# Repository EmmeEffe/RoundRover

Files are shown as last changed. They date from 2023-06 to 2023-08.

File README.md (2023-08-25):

# RoundRover
Star Wars BB8-style 3D Printed Robot

Designed and developed by [Lorenzo Cicali](https://www.github.com/Lorentz99), [Ginevra Dazzi](https://www.github.com/Gine99), [Tommaso Matteuzzi](https://www.github.com/tommasomatt) and [Martino Falorni](https://www.github.com/EmmeEffe),

---
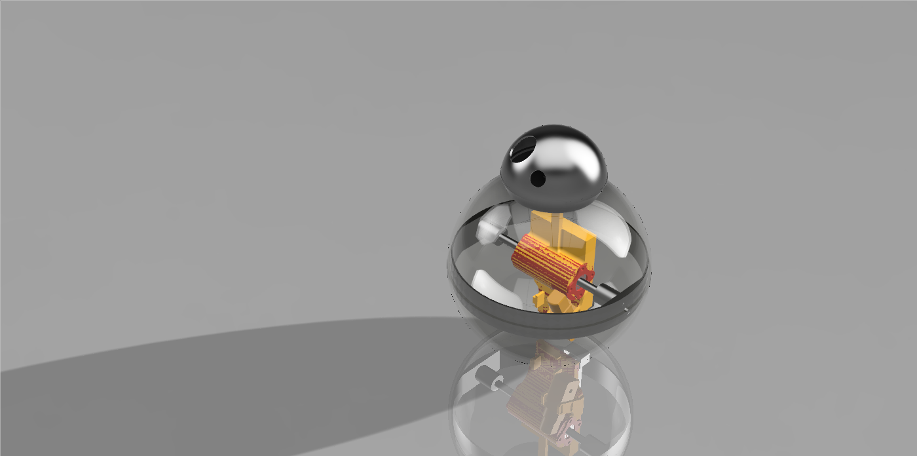
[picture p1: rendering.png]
rendering


## Goal
The project has been realized for the Automation Control Laboratory exam at University of Florence.

You can find the video of the project below: 

Design of a Spherical Robot BB8 with Arduino and Simulink (http://www.youtube.com/watch?v=LbQrJQIPuXo "Design of a Spherical Robot BB8 with Arduino and Simulink")

## Printing
You can use a 3D FDM Printer to print all the pieces for the project. 
We have printed them in PLA.

You can find the files in the [StlFiles](StlFiles/) folder.

You have to fill the balancer with lead balls ad glue the cover onto it:
- [Balancer Leg](StlFiles/balancer_leg.stl)
- [Balancer Cover](StlFiles/balancer_cover.stl)

Then print the transmission gears. Thoose are made for a 2.5mm belt
- [Big Gear](StlFiles/bigGear.stl)
- [Small Gear](StlFiles/smallGear.stl)

Then print the main body with the external ring
- [Main Body](StlFiles/body.stl)
- [External Ring](StlFiles/ring.stl)
- [Bearing Holder](StlFiles/bearingHolder.stl) (print 2 times)

## Parts
- Mechanic Hardware
  - 2 x plastic semisphere, diameter 200 mm
  - 1x Metal shaft, 160 mm, 8 mm ø
  - 2x Metal ball bearing, 8x22x7mm
  - 1x Transmission belt 2.5T
  - fishing Lead weights
  - Neodimium Magnets
  - bolts and nuts
  - threaded inserts for 3d prints
- Electronic Hardware
  - 9V battery
  - H-bridge board MX1616H
  - ESP32 board
  - IMU system MPU-6050
  - Servomotor 9g
  - Gear motor, DC, supply voltage 3-12 Volt, 200 rpm

## Circuit
We have realized the circuit on a perfboard following the schematic below:

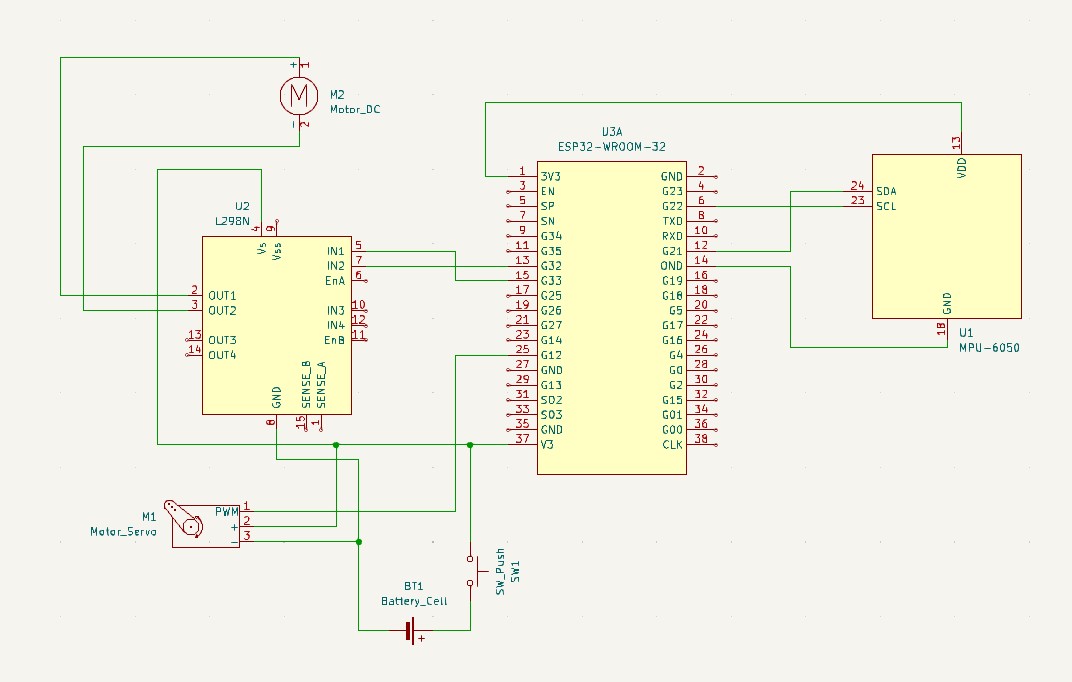
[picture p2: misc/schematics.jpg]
schematics


## Software 
The software is coded in Simulink. You can find all the code in the [SimulinkFiles](SimulinkFiles) folder.

[controlSystem.slx](SimulinkFiles/controlSystem.slx) has to be loaded onto the ESP32 board, [RemoteController.slx](SimulinkFiles/RemoteController.slx) will go on an Android device and is used to control the robot.

# Authors
Designed and developed by [Lorenzo Cicali](https://www.github.com/Lorentz99), [Ginevra Dazzi](https://www.github.com/Gine99), [Tommaso Matteuzzi](https://www.github.com/tommasomatt) and [Martino Falorni](https://www.github.com/EmmeEffe)

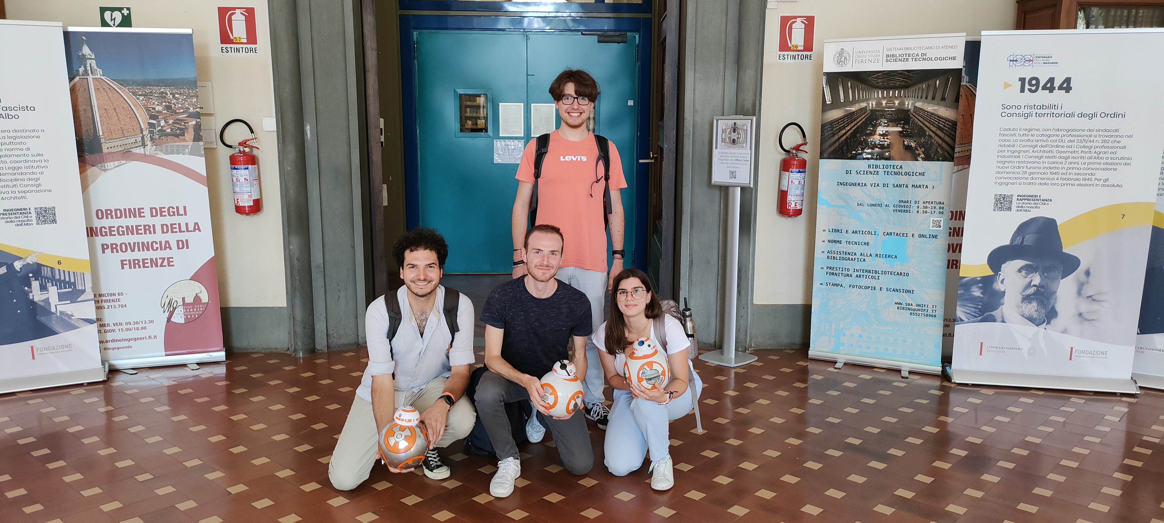
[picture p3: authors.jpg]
authors


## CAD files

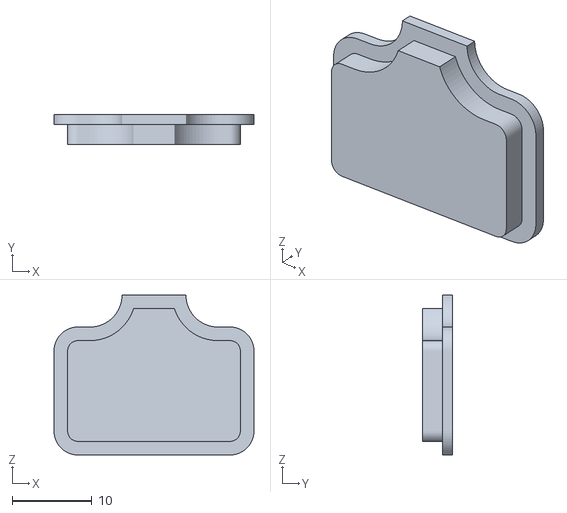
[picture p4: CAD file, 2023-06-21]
StlFiles/balancer_cover.stl
25.0 x 3.70 x 20.0

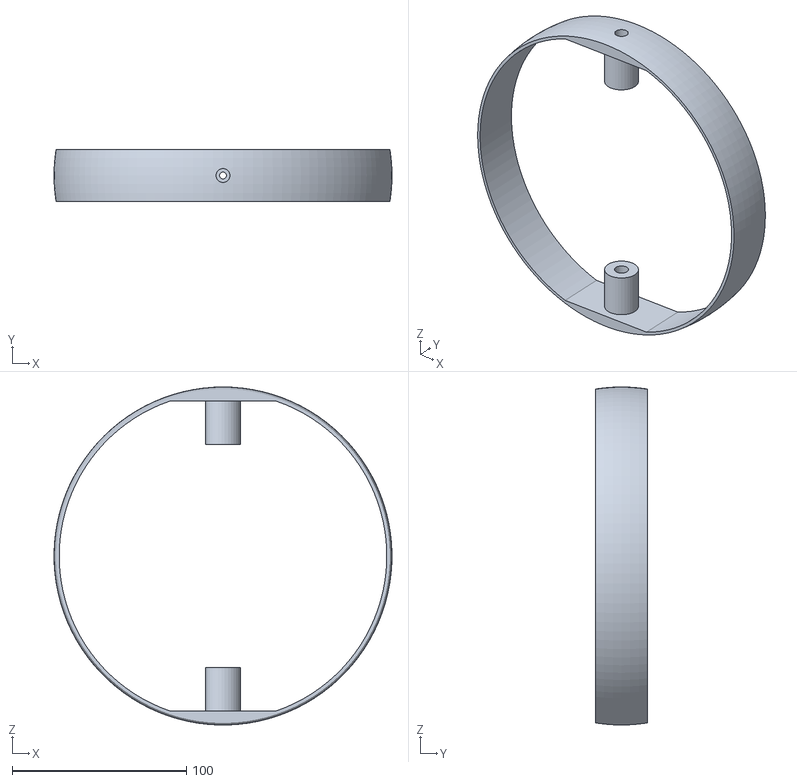
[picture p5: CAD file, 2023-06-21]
StlFiles/ring.stl
194.0 x 30.0 x 193.8

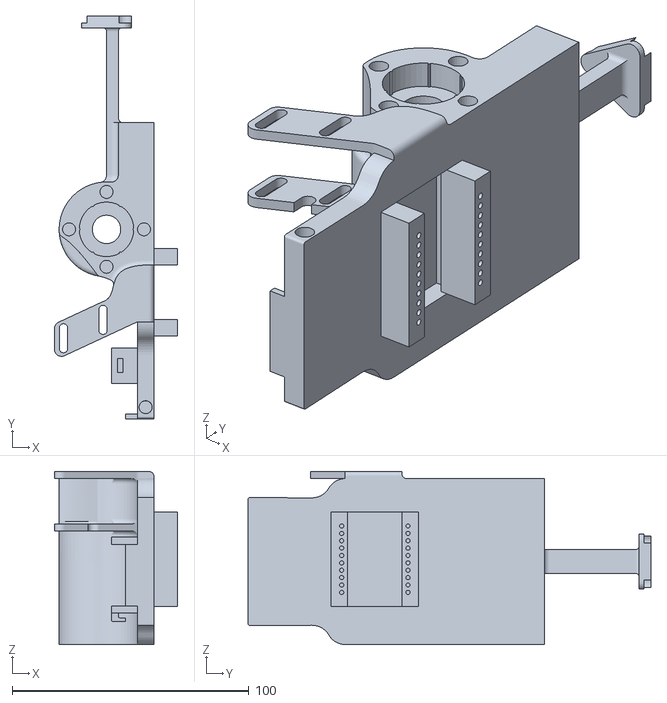
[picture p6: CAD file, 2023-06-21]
StlFiles/body.stl
52.0 x 170.0 x 73.0

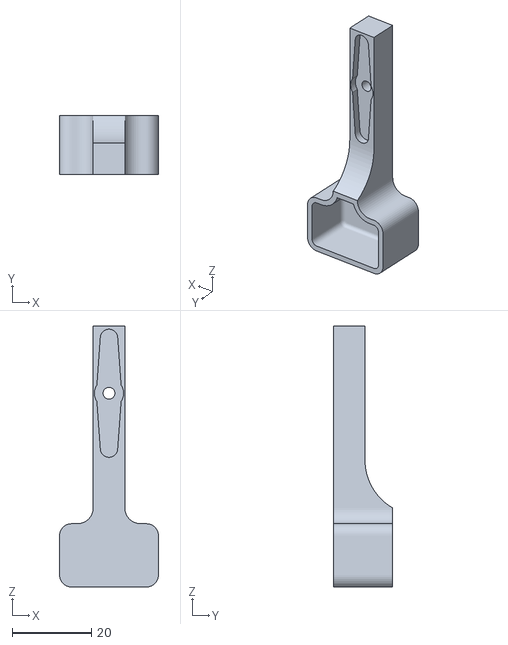
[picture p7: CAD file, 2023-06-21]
StlFiles/balancer_leg.stl
25.0 x 15.0 x 66.0

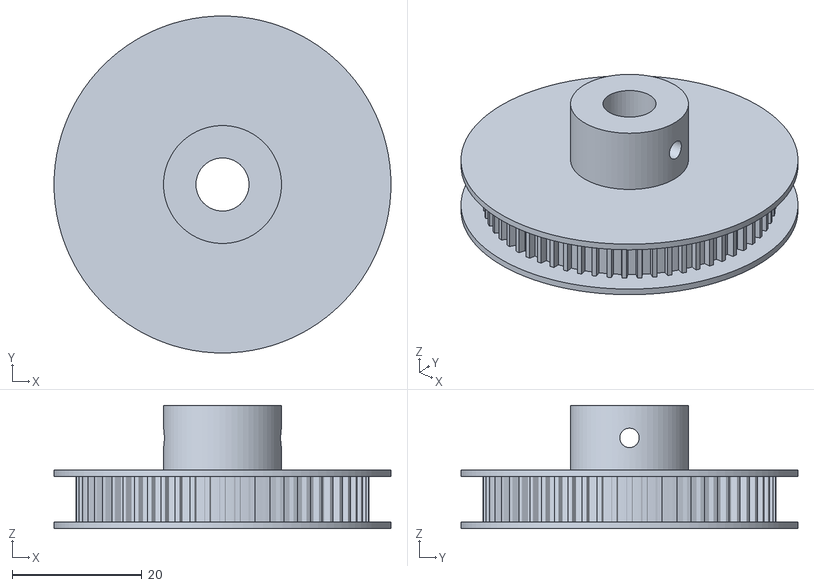
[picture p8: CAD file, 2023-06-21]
StlFiles/bigGear.stl
52.0 x 52.0 x 19.0

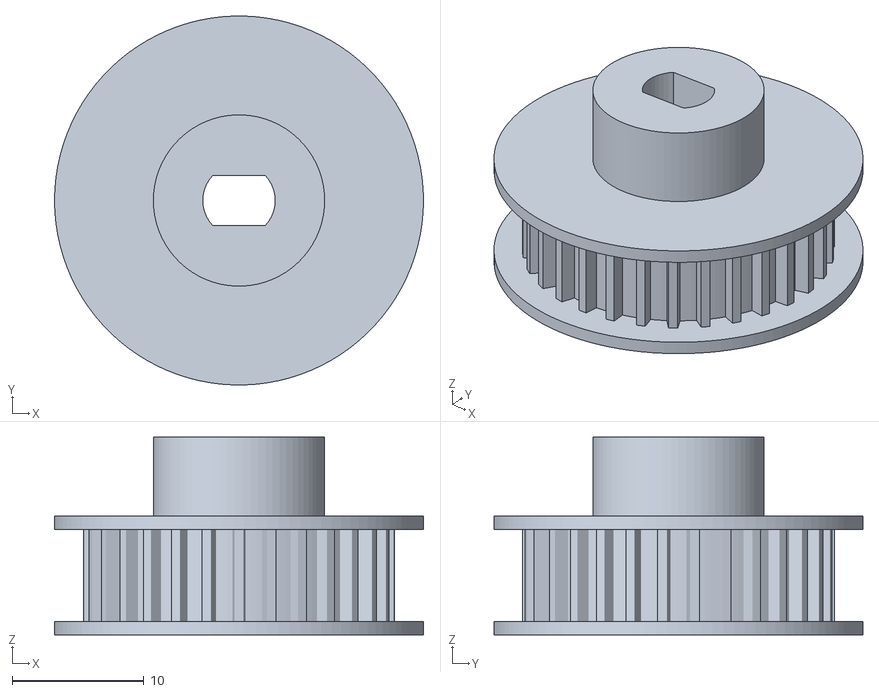
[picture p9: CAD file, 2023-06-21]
StlFiles/smallGear.stl
28.0 x 28.0 x 15.0

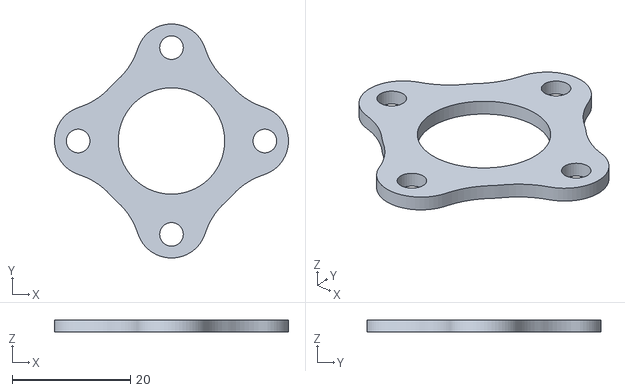
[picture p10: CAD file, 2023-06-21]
StlFiles/bearingHolder.stl
39.6 x 39.6 x 2.00

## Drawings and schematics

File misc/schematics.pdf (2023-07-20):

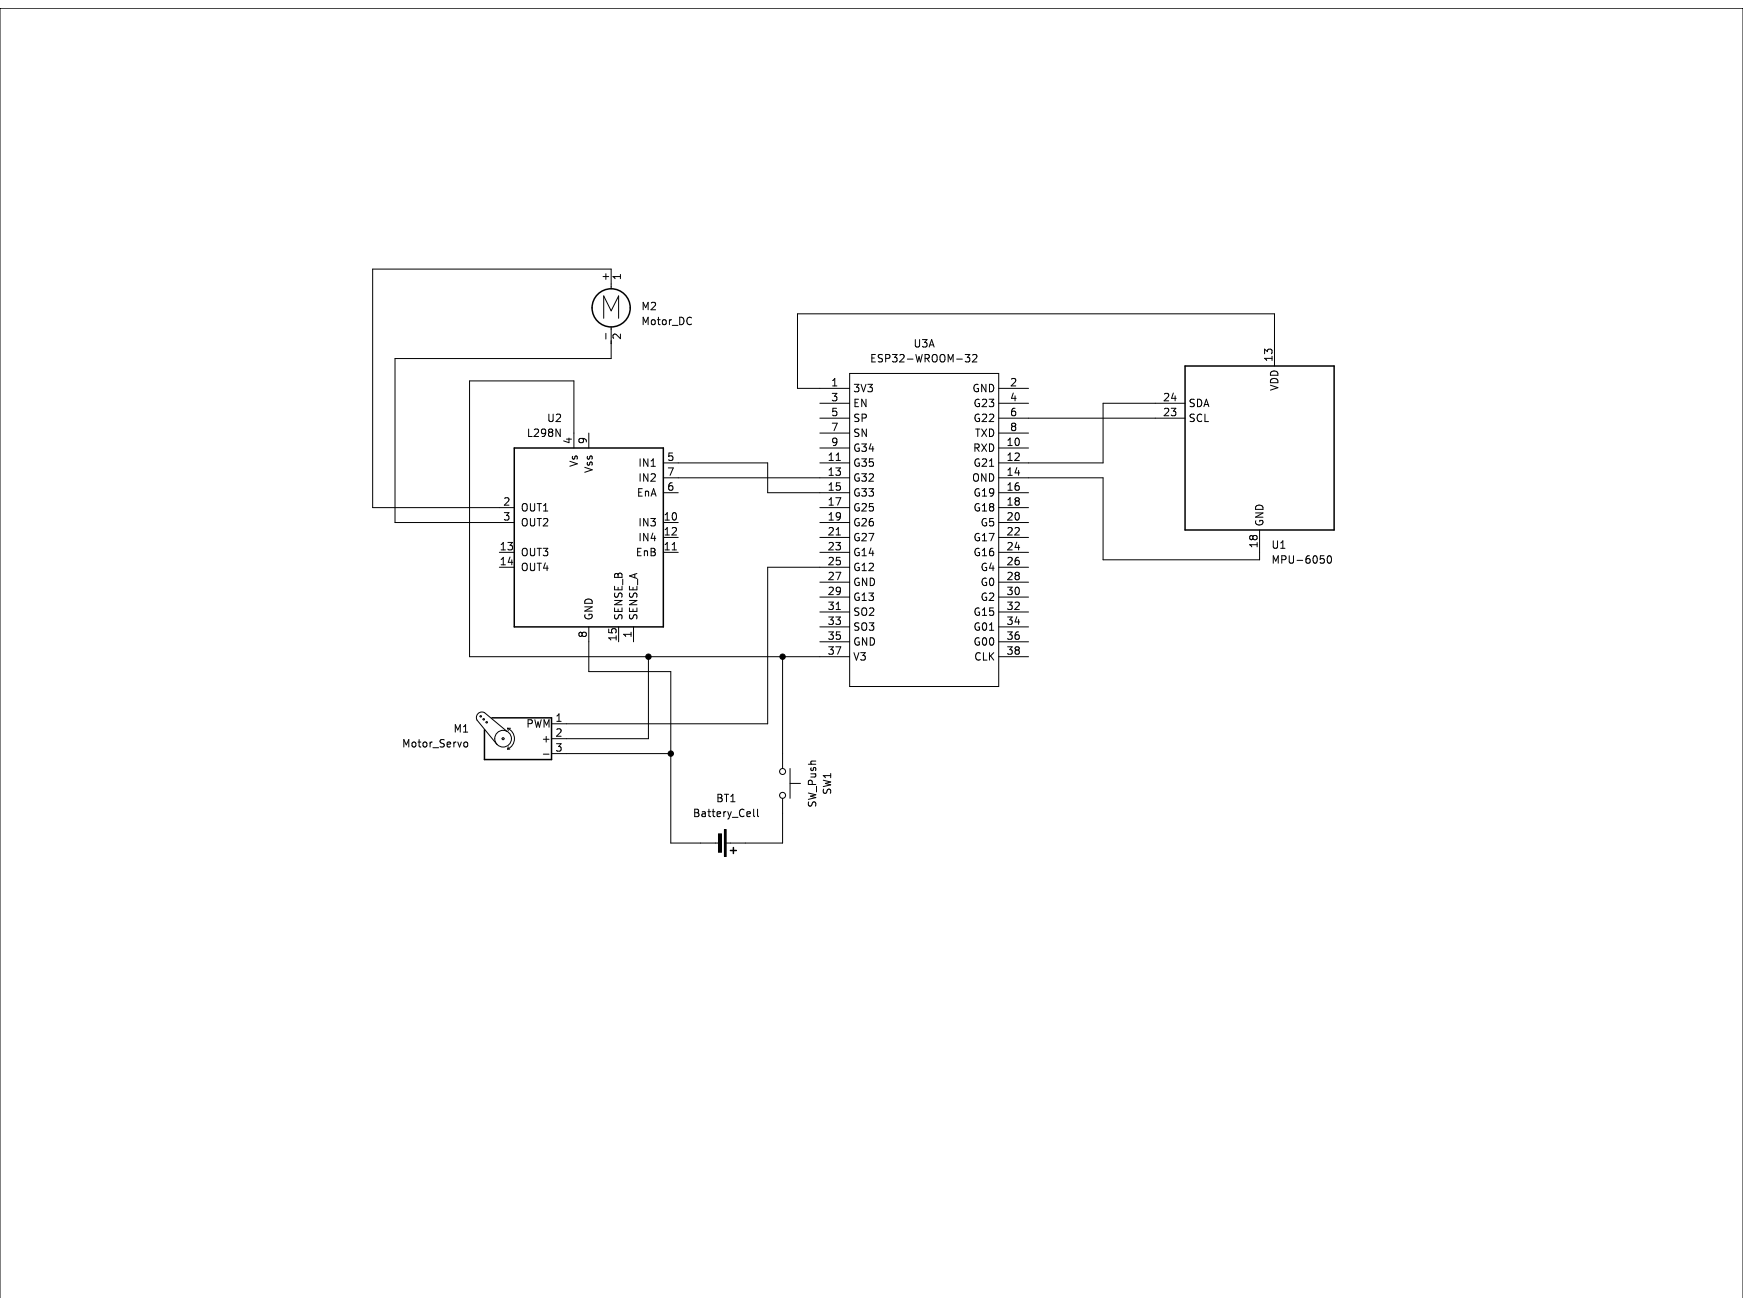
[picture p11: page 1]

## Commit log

2023-06-21 Added stl Files
    [balancer_cover.stl, balancer_leg.stl, bearingHolder.stl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]
2023-06-21 Added Printing Description
2023-06-22 Compensated Motor Dead Zone
2023-07-05 Received MQTT signal
    signal with a single MQTT block to receive data needed for calibration
2023-07-20 Added Schematics
2023-07-20 Added jpeg version of schematics
2023-08-25 Inserted Video
